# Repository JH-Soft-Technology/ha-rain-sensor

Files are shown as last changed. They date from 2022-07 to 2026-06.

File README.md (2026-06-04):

# Rain sensor for Home Assistant

A DIY wireless rain gauge built around a **Wemos D1 mini (ESP8266)** and the
**MS-WH-SP-RG** tipping-bucket sensor. It measures precipitation and reports it
to [Home Assistant](https://www.home-assistant.io/) over MQTT — with automatic
discovery, a built-in web dashboard, and over-the-air firmware updates.

- 🌧 **Accurate tip counting** — hardware interrupt with software debounce
- 📊 **Rich statistics** — total, rate (mm/h), today / week / month / year
- 🏠 **Home Assistant MQTT discovery** — entities appear automatically
- 🌐 **Built-in web dashboard** — live charts, served straight from the device
- 🔧 **Captive-portal setup** — pick WiFi + enter MQTT, no credentials in code
- ⬆️ **OTA updates** — flash new firmware from the browser
- ⏱ **NTP time sync** — correct daily / weekly / monthly / yearly resets

## Demo

You can try the device's web interface without any hardware — it is a static
snapshot of the real dashboard:

▶️ **[Live demo](https://htmlpreview.github.io/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)**

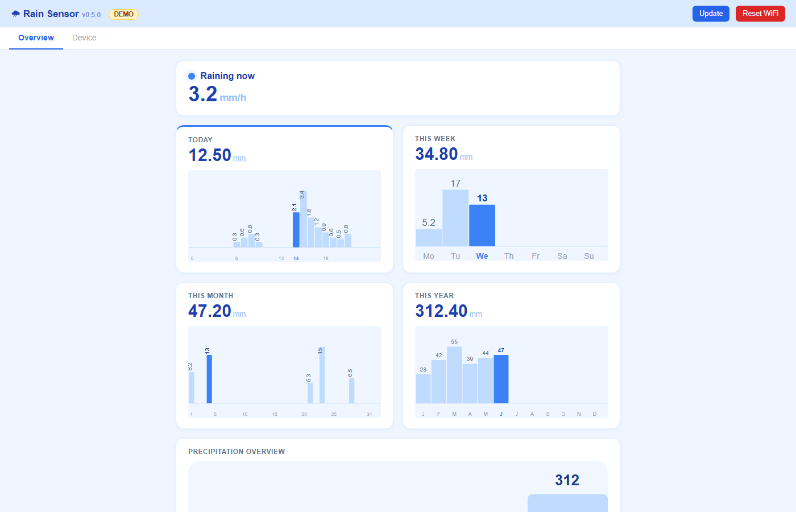
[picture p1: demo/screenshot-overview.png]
Web dashboard overview


## What's in this repository

| Path | Contents |
|---|---|
| `src/` | Firmware source (`main.cpp`) |
| `demo/` | Static preview of the web dashboard + screenshot |
| `home-assistant/` | Ready-to-use Home Assistant dashboard template |
| `3d_print/` | STL files for the sensor mount |
| `content/` | Wiring schematic and other images |
| `platformio.ini` | PlatformIO build configuration |
| `firmware-x.y.z.bin` | Pre-built firmware for OTA flashing |

## Used hardware

- Rain bucket sensor [MS-WH-SP-RG](https://www.laskakit.cz/ms-wh-sp-rg-srazkomer/)
- [Wemos D1 mini](https://www.laskakit.cz/wemos-d1-mini-esp8266-wifi-modul/) development board (4 MB flash, needed for OTA)

## Wiring

The rain gauge uses a reed (magnetic) switch on a ~2.9 m cable. The firmware
debounces the signal in software, but on a long cable a single noise spike can
be miscounted as a tip when using interrupts. A simple RC filter on the input is
recommended:

- `10 kΩ` pull-up from D1 to 3V3 (lower impedance than the internal pull-up)
- `100 nF` capacitor from D1 to GND (RC low-pass that smooths noise spikes)
- `1 kΩ` resistor in series with the reed switch (limits the capacitor's
  discharge current and protects the reed contacts)

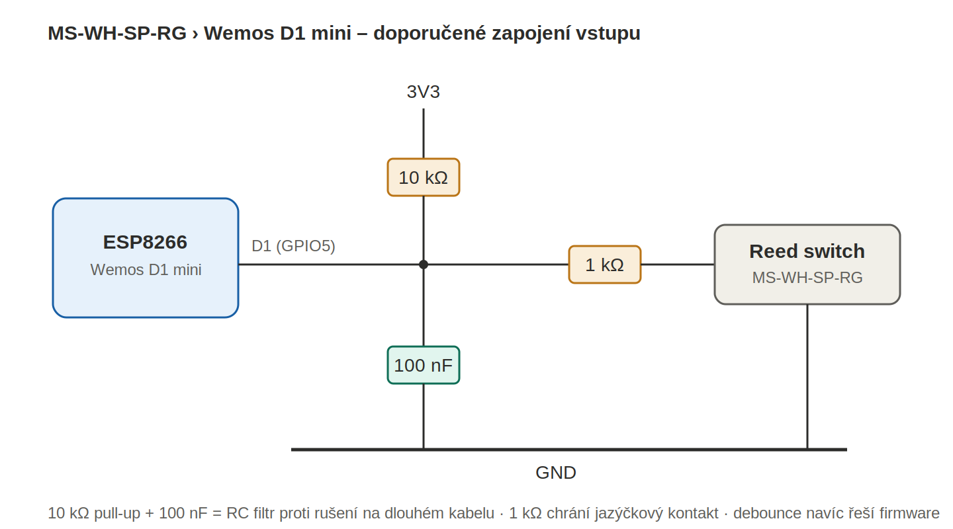
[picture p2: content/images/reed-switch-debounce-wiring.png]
Recommended input wiring


For a short cable next to the board the internal `INPUT_PULLUP` plus the
software debounce is usually enough.

## First-time setup (captive portal)

No credentials are stored in the source code. WiFi and MQTT are configured
through a captive portal on first boot:

1. Install the [MQTT](https://www.home-assistant.io/integrations/mqtt/) integration in Home Assistant and configure the broker.
2. Build and flash the firmware via PlatformIO (4 MB board, `littlefs` filesystem), or upload a pre-built `firmware-x.y.z.bin`.
3. On first boot the device opens a WiFi access point named **`RainSensor-Setup`**. Connect to it with a phone or laptop.
4. In the portal, pick your WiFi network, enter its password, and fill in the MQTT host, port, user and password. Save.
5. The device reboots, connects, and a new rain sensor device appears in the MQTT integration automatically.

Settings are stored on the device (LittleFS), so they survive reboots and
firmware updates.

## Web dashboard and OTA updates

Once connected, the device serves a dashboard on its IP address (shown in the
serial log and your router). It has two tabs:

- **Overview** — "raining now" with current rate, plus today / week / month / year totals, each with a bar chart.
- **Device** — IP address, WiFi signal, MQTT status, uptime, free memory and total rain since boot.

Two actions are available from the header:

- **Update** (`/update`) — upload a new firmware `.bin` straight from the browser (ElegantOTA).
- **Reset WiFi** (`/resetwifi`) — clear WiFi settings and reopen the setup portal.

The [live demo](https://htmlpreview.github.io/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) shows exactly this interface.

## Entities exposed in Home Assistant

All values are sent in a single JSON message and split into entities via value
templates, so the device only publishes one MQTT message per update.

| Entity | Type | Unit | Notes |
|---|---|---|---|
| Rain | sensor | mm | cumulative, `state_class: total_increasing` |
| Rain rate | sensor | mm/h | `device_class: precipitation_intensity` |
| Rain today | sensor | mm | resets at local midnight |
| Rain this week | sensor | mm | resets Monday |
| Rain this month | sensor | mm | resets on the 1st |
| Rain this year | sensor | mm | resets on Jan 1 |
| Raining | binary_sensor | — | on while it rained in the last 6 min |
| WiFi signal | sensor | dBm | diagnostic |
| Uptime | sensor | s | diagnostic |
| Free memory | sensor | B | diagnostic |

The period totals reset on real calendar boundaries thanks to **NTP time sync**
(CET/CEST). The cumulative rain uses `total_increasing`, so Home Assistant
tracks resets (after a reboot) and can build its own long-term statistics.

The send interval adapts automatically: **every 60 s** while it is raining,
**every 30 min** after 20 minutes without rain.

## Recreate the device dashboard in Home Assistant

The per-hour / per-day / per-month bar charts you see on the device are rendered
locally and are **not** sent over MQTT — there is no need to. Home Assistant can
rebuild them from the cumulative `Rain` sensor (`total_increasing`), which feeds
HA's long-term statistics.

A ready-to-use template is provided in
[`home-assistant/rain-sensor-homeassistant.yaml`](home-assistant/rain-sensor-homeassistant.yaml). It contains:

- `utility_meter` helpers for today / week / month / year (HA-side resets)
- a Lovelace dashboard mirroring the device's **Overview** and **Device** tabs, with bar charts built from the built-in `statistics-graph` card (no HACS required)
- an optional ApexCharts variant for nicer bars

Check the entity IDs at the top of the file against your install
(Settings → Devices & Services → Entities) before pasting it in.

## Build and development

- [Visual Studio Code](https://code.visualstudio.com/) with the [PlatformIO](https://platformio.org/) extension.
- Open the project, connect the Wemos D1 mini, and run *Upload*. After the first flash, further updates can be done over WiFi from the `/update` page.

## STL files

Pipe holder (50 mm diameter) with an arm to hold the rain sensor. Uses 6 M4
screws with nuts; the sensor is bolted to the arm with a self-tapping screw.

- [Pipe holder part 1](https://github.com/JH-Soft-Technology/ha-rain-sensor/blob/master/3d_print/rain%20sensor%20tube%20holder%20part%201.stl)
- [Pipe holder part 2](https://github.com/JH-Soft-Technology/ha-rain-sensor/blob/master/3d_print/rain%20sensor%20tube%20holder%20part%202.stl)
- [Arm holder](https://github.com/JH-Soft-Technology/ha-rain-sensor/blob/master/3d_print/Rain%20sensor%20arm.stl)

---

buy me a coffee (https://www.buymeacoffee.com/jhoralek)

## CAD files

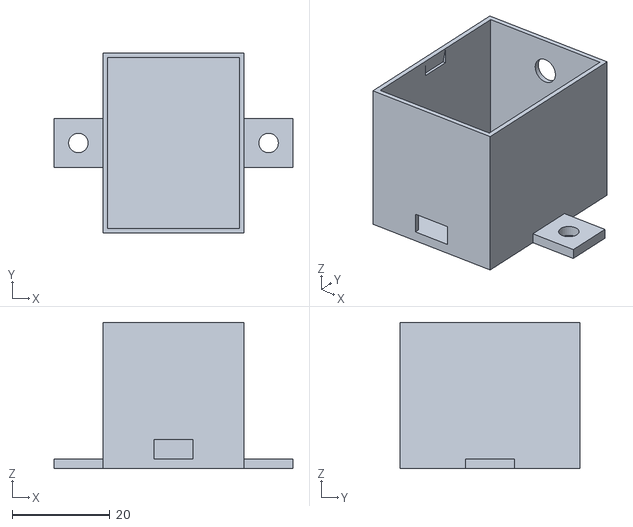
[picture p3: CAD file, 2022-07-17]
3d_print/wemos d1 mini box.stl
49.0 x 37.0 x 30.0

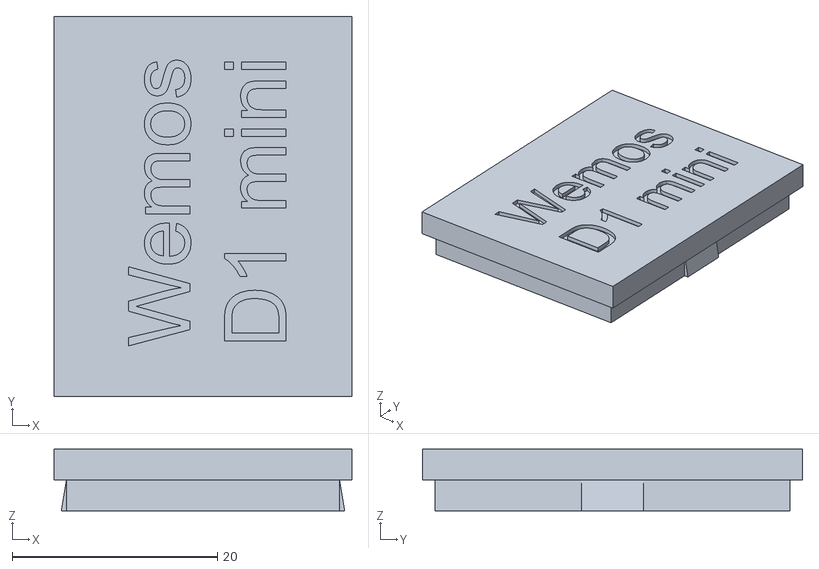
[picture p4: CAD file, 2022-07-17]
3d_print/wemos d1 mini box lid.stl
29.0 x 37.0 x 6.00

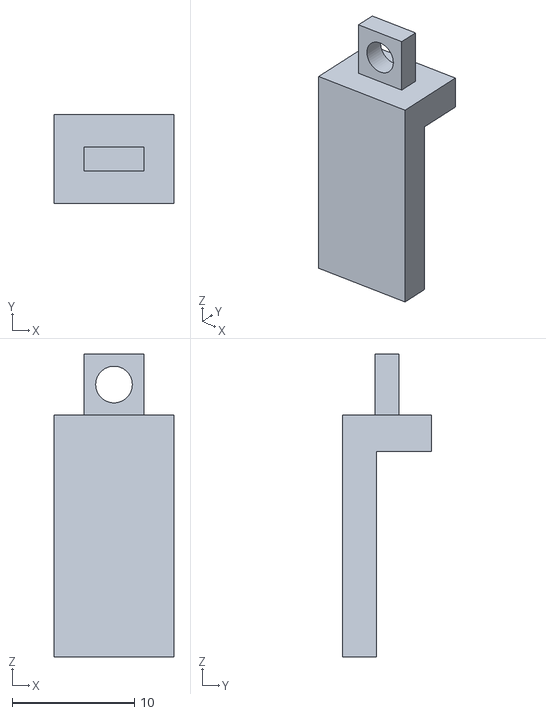
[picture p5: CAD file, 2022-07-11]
3d_print/rain sensor secure pin.stl
9.80 x 7.30 x 24.8

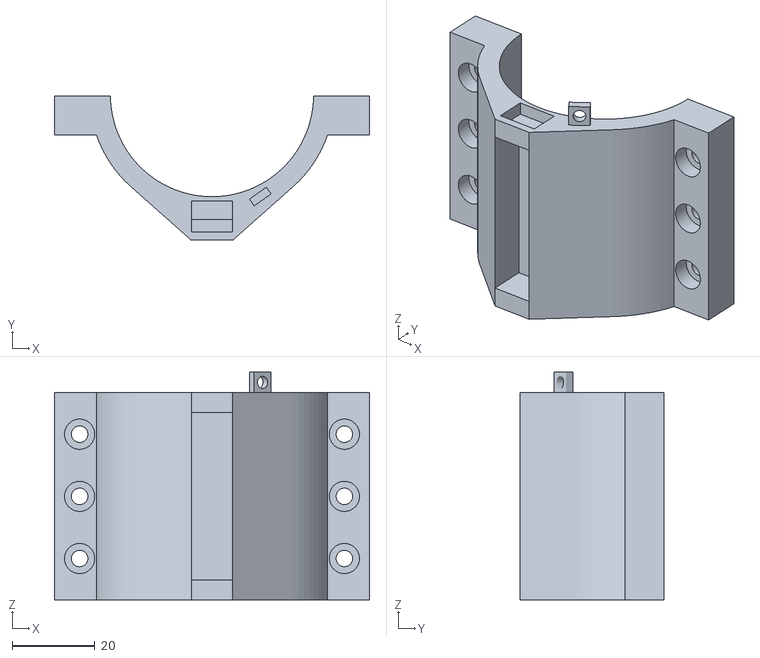
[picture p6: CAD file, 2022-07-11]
3d_print/rain sensor tube holder part 1.stl
76.0 x 34.9 x 55.0

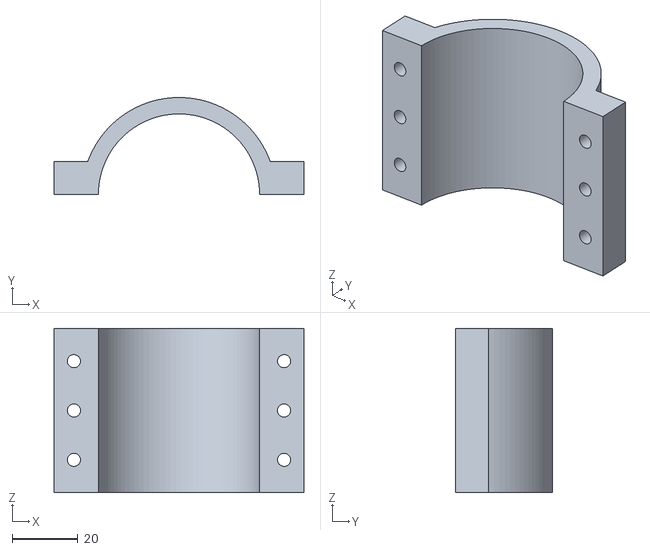
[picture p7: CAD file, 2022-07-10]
3d_print/rain sensor tube holder part 2.stl
76.0 x 29.5 x 50.0

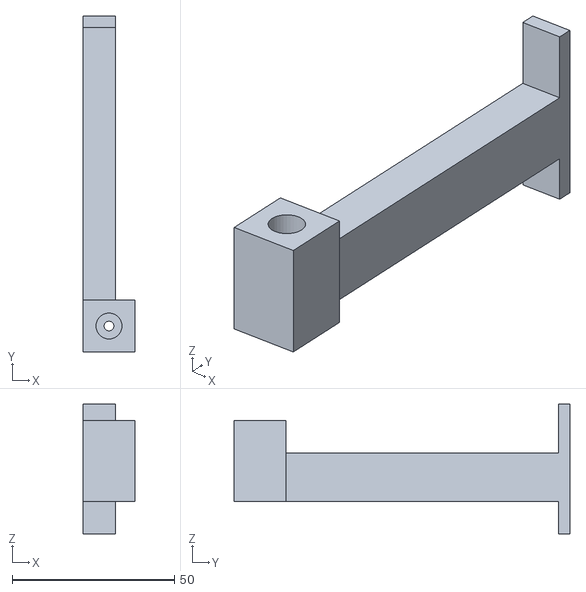
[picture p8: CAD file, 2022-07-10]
3d_print/Rain sensor arm.stl
16.0 x 103.5 x 40.0

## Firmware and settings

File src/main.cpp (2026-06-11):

/*
  Rain sensor for Home Assistant based on MQTT discovery.

  Features:
    - WiFi + MQTT configuration via a captive portal (WiFiManager),
      no credentials are stored in source code.
    - Web UI with live status, precipitation period totals, firmware
      update (ElegantOTA) and a "reset WiFi" button.
    - NTP time sync (CET/CEST) for daily/weekly/monthly/yearly reset.
    - Period stats (today/week/month/year) persisted to LittleFS.
    - One JSON state message exposed in HA as several entities:
      cumulative rain (mm), rain rate (mm/h), raining (binary),
      today/week/month/year rain, WiFi RSSI, uptime and free heap.

  author: Jiri Horalek
  email: horalek.jiri@gmail.com
  site: https://github.com/JH-Soft-Technology/ha-rain-sensor
  version: 0.7.1
  last change: 05.06.2026
*/
#include <Arduino.h>
#include <ESP8266WiFi.h>
#include <ESP8266WebServer.h>
#include <WiFiManager.h>
#include <LittleFS.h>
#include <PubSubClient.h>
#include <ArduinoJson.h>
#include <ElegantOTA.h>
#include <time.h>

#define MODEL "rainy 0.0.2"
#define SW_VERSION "0.7.1"

#define MQTT_MAX_TRANSFER_SIZE 1024
#define MQTT_INSTANCE_NAME "ha-rain-sensor"

#define AP_NAME "RainSensor-Setup"

#define RAIN_ACTIVE_INTERVAL_S 60
#define RAIN_IDLE_INTERVAL_S 1800

// Adaptive "raining" detection. A tipping bucket is quantized (one tip =
// 0.2794 mm), so in light rain the gap between tips can be tens of minutes
// and a fixed window flickers to "not raining" between tips. Instead we
// wait ~FACTOR x the last gap between tips, clamped to [MIN, MAX]:
// heavy rain -> short timeout (turns off quickly after it stops),
// drizzle    -> long timeout  (does not flicker during long gaps).
#define RAIN_TIMEOUT_FACTOR 2
#define RAIN_MIN_TIMEOUT_MS 600000UL   // 10 min
#define RAIN_MAX_TIMEOUT_MS 3600000UL  // 60 min

#define MQTT_RECONNECT_INTERVAL_MS 5000
#define DEBOUNCE_MS 150

#define NTP_SERVER "pool.ntp.org"
#define TZ_INFO "CET-1CEST,M3.5.0,M10.5.0/3"
#define STATS_SAVE_MS 300000UL // persist period stats every 5 min

// ---- MQTT discovery topics ----
#define TOPIC_STATE "homeassistant/sensor/" MQTT_INSTANCE_NAME "/state"
#define TOPIC_AVAILABILITY "homeassistant/sensor/" MQTT_INSTANCE_NAME "/availability"
#define PAYLOAD_ONLINE "online"
#define PAYLOAD_OFFLINE "offline"

#define CFG_RAIN "homeassistant/sensor/" MQTT_INSTANCE_NAME "/rain/config"
#define CFG_RATE "homeassistant/sensor/" MQTT_INSTANCE_NAME "/rate/config"
#define CFG_RSSI "homeassistant/sensor/" MQTT_INSTANCE_NAME "/rssi/config"
#define CFG_UPTIME "homeassistant/sensor/" MQTT_INSTANCE_NAME "/uptime/config"
#define CFG_HEAP "homeassistant/sensor/" MQTT_INSTANCE_NAME "/heap/config"
#define CFG_RAINING "homeassistant/binary_sensor/" MQTT_INSTANCE_NAME "/raining/config"
#define CFG_TODAY "homeassistant/sensor/" MQTT_INSTANCE_NAME "/today/config"
#define CFG_WEEK "homeassistant/sensor/" MQTT_INSTANCE_NAME "/week/config"
#define CFG_MONTH "homeassistant/sensor/" MQTT_INSTANCE_NAME "/month/config"
#define CFG_YEAR "homeassistant/sensor/" MQTT_INSTANCE_NAME "/year/config"

// On the Wemos D1 mini (ESP8266) all GPIO pins except D0 (GPIO16)
// support hardware interrupts, so D1 works fine with attachInterrupt.
const byte RAIN_PIN = D1;
const float MM_PER_TIP = 0.2794;

// ---- persisted MQTT configuration ----
struct Config
{
  char host[40];
  char port[6];
  char user[32];
  char pass[32];
};
Config config;
bool shouldSaveConfig = false;

WiFiClient wifi;
PubSubClient mqtt(wifi);
ESP8266WebServer server(80);
WiFiManager wm;

volatile unsigned int tipping_count = 0;
volatile unsigned long last_tip_time = 0;
volatile unsigned long last_tip_interval = 0; // gap (ms) between the last two tips

float total_rain_mm = 0.0;

// Period statistics — reset daily/weekly/monthly/yearly via NTP time
float rain_today_mm = 0.0;
float rain_week_mm = 0.0;
float rain_month_mm = 0.0;
float rain_year_mm = 0.0;

// Reference timestamps stored alongside period stats in LittleFS
int ref_yday = -1;  // tm_yday at last save (0–365)
int ref_week = -1;  // ISO week number at last save
int ref_month = -1; // tm_mon at last save (0–11)
int ref_year = -1;  // tm_year at last save (years since 1900)

// Per-bucket history arrays for in-tile sparkline charts
float rain_hourly[24] = {};      // rain per hour of today     (index = tm_hour)
float rain_daily_week[7] = {};   // rain per weekday Mon–Sun   (index = (wday+6)%7)
float rain_daily_month[31] = {}; // rain per day of month      (index = tm_mday-1)
float rain_monthly[12] = {};     // rain per month of year     (index = tm_mon)

int hist_hour = -1; // current accumulation bucket indices (updated each minute)
int hist_wday = -1;
int hist_mday = -1;
int hist_mon = -1;

unsigned long last_send_rain = 0;
unsigned long last_mqtt_attempt = 0;
unsigned long last_stats_save = 0;
unsigned long last_rollover_chk = 0;

// ---- ISR + tip helpers ----

IRAM_ATTR void count_tipping()
{
  unsigned long now = millis();
  if (now - last_tip_time > DEBOUNCE_MS)
  {
    if (last_tip_time != 0) last_tip_interval = now - last_tip_time;
    tipping_count++;
    last_tip_time = now;
  }
}

unsigned int peek_tips()
{
  noInterrupts();
  unsigned int c = tipping_count;
  interrupts();
  return c;
}

void consume_tips(unsigned int n)
{
  noInterrupts();
  tipping_count -= n;
  interrupts();
}

// How long without a tip until we decide it stopped raining. Scales with
// the last gap between tips so light rain doesn't flicker, clamped so heavy
// rain turns off promptly and a lone tip doesn't latch "raining" forever.
unsigned long rain_timeout_ms()
{
  unsigned long t = (unsigned long)RAIN_TIMEOUT_FACTOR * last_tip_interval;
  if (t < RAIN_MIN_TIMEOUT_MS) t = RAIN_MIN_TIMEOUT_MS;
  if (t > RAIN_MAX_TIMEOUT_MS) t = RAIN_MAX_TIMEOUT_MS;
  return t;
}

boolean raining_now()
{
  if (last_tip_time == 0) return false; // no tip ever -> not raining
  return (millis() - last_tip_time) < rain_timeout_ms();
}

// Rain rate (mm/h) derived from the interval between tips, not from counting
// tips in a fixed window. A tipping bucket is quantized (one tip = 0.2794 mm),
// so counting per minute reads 0 between tips and spikes on the tip. Using the
// gap between tips gives a smooth value: rate = mm_per_tip / gap. As time since
// the last tip grows past that gap, the rate decays; once raining_now() expires
// it returns 0.
float rain_rate_mm_h()
{
  if (last_tip_interval == 0) return 0.0; // need >= 2 tips to know a rate
  if (!raining_now()) return 0.0;         // rain stopped (adaptive timeout)
  unsigned long since = millis() - last_tip_time;
  unsigned long gap = (since > last_tip_interval) ? since : last_tip_interval;
  return MM_PER_TIP / (gap / 3600000.0);
}

// ---- Time helpers ----

boolean get_localtime(struct tm &ti)
{
  time_t now = time(nullptr);
  if (now < 1000000000UL)
    return false;
  localtime_r(&now, &ti);
  return true;
}

// Monday-based ISO week number (strftime %W).
int week_num(const struct tm &ti)
{
  char buf[4];
  strftime(buf, sizeof(buf), "%W", &ti);
  return atoi(buf);
}

void sync_ntp()
{
  configTime(0, 0, NTP_SERVER);
  setenv("TZ", TZ_INFO, 1);
  tzset();
  Serial.print("Waiting for NTP ...");
  time_t now = 0;
  for (int i = 0; i < 50 && now < 1000000000UL; i++)
  {
    delay(100);
    time(&now);
  }
  Serial.println(now > 1000000000UL ? " OK" : " failed");
}

// ---- Period-stats persistence (LittleFS /stats.json) ----

void load_stats()
{
  if (!LittleFS.exists("/stats.json"))
    return;
  File f = LittleFS.open("/stats.json", "r");
  if (!f)
    return;
  DynamicJsonDocument doc(400);
  if (deserializeJson(doc, f))
  {
    f.close();
    return;
  }
  f.close();
  total_rain_mm = doc["total"] | 0.0f;
  rain_today_mm = doc["today"] | 0.0f;
  rain_week_mm = doc["week"] | 0.0f;
  rain_month_mm = doc["month"] | 0.0f;
  rain_year_mm = doc["yr"] | 0.0f;
  ref_yday = doc["yday"] | -1;
  ref_week = doc["wk"] | -1;
  ref_month = doc["mon"] | -1;
  ref_year = doc["year"] | -1;
}

void save_stats()
{
  DynamicJsonDocument doc(400);
  doc["total"] = total_rain_mm;
  doc["today"] = rain_today_mm;
  doc["week"] = rain_week_mm;
  doc["month"] = rain_month_mm;
  doc["yr"] = rain_year_mm;
  doc["yday"] = ref_yday;
  doc["wk"] = ref_week;
  doc["mon"] = ref_month;
  doc["year"] = ref_year;
  File f = LittleFS.open("/stats.json", "w");
  if (!f)
    return;
  serializeJson(doc, f);
  f.close();
}

void save_history(); // defined below, forward-declared for check_rollover

// Reset period accumulators that have rolled over since the last save.
void check_rollover()
{
  struct tm ti;
  if (!get_localtime(ti))
    return;

  int cur_yday = ti.tm_yday;
  int cur_week = week_num(ti);
  int cur_month = ti.tm_mon;
  int cur_year = ti.tm_year;

  // Always keep current-bucket indices up to date
  hist_hour = ti.tm_hour;
  hist_wday = (ti.tm_wday + 6) % 7; // Mon=0 … Sun=6
  hist_mday = ti.tm_mday - 1;
  hist_mon = ti.tm_mon;

  if (ref_year == -1)
  {
    ref_yday = cur_yday;
    ref_week = cur_week;
    ref_month = cur_month;
    ref_year = cur_year;
    save_stats();
    return;
  }

  bool changed = false;

  if (cur_year != ref_year)
  {
    rain_year_mm = rain_month_mm = rain_week_mm = rain_today_mm = 0;
    memset(rain_monthly, 0, sizeof(rain_monthly));
    memset(rain_daily_month, 0, sizeof(rain_daily_month));
    memset(rain_daily_week, 0, sizeof(rain_daily_week));
    memset(rain_hourly, 0, sizeof(rain_hourly));
    ref_year = cur_year;
    ref_month = cur_month;
    ref_week = cur_week;
    ref_yday = cur_yday;
    changed = true;
  }
  else if (cur_month != ref_month)
  {
    rain_month_mm = rain_week_mm = rain_today_mm = 0;
    memset(rain_daily_month, 0, sizeof(rain_daily_month));
    memset(rain_daily_week, 0, sizeof(rain_daily_week));
    memset(rain_hourly, 0, sizeof(rain_hourly));
    ref_month = cur_month;
    ref_week = cur_week;
    ref_yday = cur_yday;
    changed = true;
  }
  else if (cur_week != ref_week)
  {
    rain_week_mm = rain_today_mm = 0;
    memset(rain_daily_week, 0, sizeof(rain_daily_week));
    memset(rain_hourly, 0, sizeof(rain_hourly));
    ref_week = cur_week;
    ref_yday = cur_yday;
    changed = true;
  }
  else if (cur_yday != ref_yday)
  {
    rain_today_mm = 0;
    memset(rain_hourly, 0, sizeof(rain_hourly));
    ref_yday = cur_yday;
    changed = true;
  }

  if (changed)
  {
    save_stats();
    save_history();
  }
}

// ---- MQTT configuration persistence (LittleFS /config.json) ----

boolean load_config()
{
  if (!LittleFS.exists("/config.json"))
    return false;
  File f = LittleFS.open("/config.json", "r");
  if (!f)
    return false;
  DynamicJsonDocument doc(512);
  DeserializationError err = deserializeJson(doc, f);
  f.close();
  if (err)
    return false;
  strlcpy(config.host, doc["host"] | "", sizeof(config.host));
  strlcpy(config.port, doc["port"] | "1883", sizeof(config.port));
  strlcpy(config.user, doc["user"] | "", sizeof(config.user));
  strlcpy(config.pass, doc["pass"] | "", sizeof(config.pass));
  return true;
}

void save_config()
{
  DynamicJsonDocument doc(512);
  doc["host"] = config.host;
  doc["port"] = config.port;
  doc["user"] = config.user;
  doc["pass"] = config.pass;
  File f = LittleFS.open("/config.json", "w");
  if (!f)
  {
    Serial.println("Failed to open config file for writing");
    return;
  }
  serializeJson(doc, f);
  f.close();
  Serial.println("Config saved");
}

void load_history()
{
  if (!LittleFS.exists("/history.json"))
    return;
  File f = LittleFS.open("/history.json", "r");
  if (!f)
    return;
  DynamicJsonDocument doc(1024);
  if (deserializeJson(doc, f))
  {
    f.close();
    return;
  }
  f.close();
  JsonArray ah = doc["h"].as<JsonArray>();
  JsonArray aw = doc["w"].as<JsonArray>();
  JsonArray am = doc["m"].as<JsonArray>();
  JsonArray ay = doc["y"].as<JsonArray>();
  for (int i = 0; i < (int)ah.size() && i < 24; i++)
    rain_hourly[i] = ah[i] | 0.0f;
  for (int i = 0; i < (int)aw.size() && i < 7; i++)
    rain_daily_week[i] = aw[i] | 0.0f;
  for (int i = 0; i < (int)am.size() && i < 31; i++)
    rain_daily_month[i] = am[i] | 0.0f;
  for (int i = 0; i < (int)ay.size() && i < 12; i++)
    rain_monthly[i] = ay[i] | 0.0f;
}

void save_history()
{
  DynamicJsonDocument doc(1024);
  JsonArray ah = doc.createNestedArray("h");
  JsonArray aw = doc.createNestedArray("w");
  JsonArray am = doc.createNestedArray("m");
  JsonArray ay = doc.createNestedArray("y");
  for (int i = 0; i < 24; i++)
    ah.add(round(rain_hourly[i] * 100) / 100.0f);
  for (int i = 0; i < 7; i++)
    aw.add(round(rain_daily_week[i] * 100) / 100.0f);
  for (int i = 0; i < 31; i++)
    am.add(round(rain_daily_month[i] * 100) / 100.0f);
  for (int i = 0; i < 12; i++)
    ay.add(round(rain_monthly[i] * 100) / 100.0f);
  File f = LittleFS.open("/history.json", "w");
  if (!f)
    return;
  serializeJson(doc, f);
  f.close();
}

void save_config_callback() { shouldSaveConfig = true; }

// ---- Home Assistant MQTT discovery ----

void add_device_info(JsonObject device)
{
  JsonArray ids = device.createNestedArray("ids");
  ids.add(MQTT_INSTANCE_NAME);
  device["mf"] = "JH SOFT Technology";
  device["mdl"] = MODEL;
  device["name"] = "Rain sensor";
  device["sw"] = SW_VERSION;
}

DynamicJsonDocument build_sensor_config(const char *name, const char *uniq,
                                        const char *val_tpl, const char *unit,
                                        const char *dev_cla, const char *stat_cla,
                                        const char *icon, boolean diagnostic)
{
  DynamicJsonDocument c(1024);
  c["name"] = name;
  c["uniq_id"] = uniq;
  c["stat_t"] = TOPIC_STATE;
  c["val_tpl"] = val_tpl;
  if (unit)
    c["unit_of_meas"] = unit;
  if (dev_cla)
    c["dev_cla"] = dev_cla;
  if (stat_cla)
    c["stat_cla"] = stat_cla;
  if (icon)
    c["icon"] = icon;
  if (diagnostic)
    c["ent_cat"] = "diagnostic";
  c["avty_t"] = TOPIC_AVAILABILITY;
  c["pl_avail"] = PAYLOAD_ONLINE;
  c["pl_not_avail"] = PAYLOAD_OFFLINE;
  add_device_info(c.createNestedObject("dev"));
  return c;
}

DynamicJsonDocument build_raining_config()
{
  DynamicJsonDocument c(1024);
  c["name"] = "Raining";
  c["uniq_id"] = "rain_sensor_raining";
  c["stat_t"] = TOPIC_STATE;
  c["val_tpl"] = "{{ 'ON' if value_json.raining else 'OFF' }}";
  c["dev_cla"] = "moisture";
  c["icon"] = "mdi:weather-pouring";
  c["avty_t"] = TOPIC_AVAILABILITY;
  c["pl_avail"] = PAYLOAD_ONLINE;
  c["pl_not_avail"] = PAYLOAD_OFFLINE;
  add_device_info(c.createNestedObject("dev"));
  return c;
}

// ---- MQTT ----

boolean mqtt_reconnect()
{
  if (mqtt.connected())
    return true;
  if (millis() - last_mqtt_attempt < MQTT_RECONNECT_INTERVAL_MS)
    return false;
  last_mqtt_attempt = millis();
  Serial.print("Connecting to mqtt broker ...");
  boolean connected;
  if (strlen(config.user) > 0)
    connected = mqtt.connect(MQTT_INSTANCE_NAME, config.user, config.pass,
                             TOPIC_AVAILABILITY, 0, true, PAYLOAD_OFFLINE);
  else
    connected = mqtt.connect(MQTT_INSTANCE_NAME, NULL, NULL,
                             TOPIC_AVAILABILITY, 0, true, PAYLOAD_OFFLINE);
  if (!connected)
  {
    Serial.print(" failed, rc=");
    Serial.println(mqtt.state());
    return false;
  }
  Serial.println(" connected");
  mqtt.publish(TOPIC_AVAILABILITY, PAYLOAD_ONLINE, true);
  return true;
}

boolean publish_config(DynamicJsonDocument doc, const char *topic)
{
  char buffer[MQTT_MAX_TRANSFER_SIZE];
  size_t n = serializeJson(doc, buffer, sizeof(buffer));
  if (!n)
  {
    Serial.println("Config serialization failed (buffer too small)");
    return false;
  }
  return mqtt.publish(topic, buffer, true);
}

void publish_discovery()
{
  publish_config(build_sensor_config(
                     "Rain", "rain_sensor",
                     "{{ value_json.rain }}", "mm",
                     "precipitation", "total_increasing", "mdi:weather-rainy", false),
                 CFG_RAIN);

  publish_config(build_sensor_config(
                     "Rain rate", "rain_sensor_rate",
                     "{{ value_json.rate }}", "mm/h",
                     "precipitation_intensity", "measurement", "mdi:weather-pouring", false),
                 CFG_RATE);

  publish_config(build_sensor_config(
                     "Rain today", "rain_sensor_today",
                     "{{ value_json.today }}", "mm",
                     "precipitation", "measurement", "mdi:weather-rainy", false),
                 CFG_TODAY);

  publish_config(build_sensor_config(
                     "Rain this week", "rain_sensor_week",
                     "{{ value_json.week }}", "mm",
                     "precipitation", "measurement", "mdi:calendar-week", false),
                 CFG_WEEK);

  publish_config(build_sensor_config(
                     "Rain this month", "rain_sensor_month",
                     "{{ value_json.month }}", "mm",
                     "precipitation", "measurement", "mdi:calendar-month", false),
                 CFG_MONTH);

  publish_config(build_sensor_config(
                     "Rain this year", "rain_sensor_year",
                     "{{ value_json.year }}", "mm",
                     "precipitation", "measurement", "mdi:calendar", false),
                 CFG_YEAR);

  publish_config(build_sensor_config(
                     "WiFi signal", "rain_sensor_rssi",
                     "{{ value_json.rssi }}", "dBm",
                     "signal_strength", "measurement", NULL, true),
                 CFG_RSSI);

  publish_config(build_sensor_config(
                     "Uptime", "rain_sensor_uptime",
                     "{{ value_json.uptime }}", "s",
                     "duration", "measurement", NULL, true),
                 CFG_UPTIME);

  publish_config(build_sensor_config(
                     "Free memory", "rain_sensor_heap",
                     "{{ value_json.heap }}", "B",
                     NULL, "measurement", "mdi:memory", true),
                 CFG_HEAP);

  publish_config(build_raining_config(), CFG_RAINING);
}

boolean publish_state()
{
  if (!mqtt.connected())
    return false;
  DynamicJsonDocument doc(384);
  doc["rain"] = round(total_rain_mm * 100) / 100.0;
  doc["rate"] = round(rain_rate_mm_h() * 10) / 10.0;
  doc["raining"] = raining_now();
  doc["rssi"] = WiFi.RSSI();
  doc["uptime"] = millis() / 1000UL;
  doc["heap"] = ESP.getFreeHeap();
  doc["today"] = round(rain_today_mm * 100) / 100.0;
  doc["week"] = round(rain_week_mm * 100) / 100.0;
  doc["month"] = round(rain_month_mm * 100) / 100.0;
  doc["year"] = round(rain_year_mm * 100) / 100.0;
  char buffer[384];
  serializeJson(doc, buffer, sizeof(buffer));
  return mqtt.publish(TOPIC_STATE, buffer, true);
}

// ---- Web UI ----

// Stream a single x-axis label for a sparkline.
void send_xlabel(int idx, int bw, int y, int hi, int xfs, const char *lbl)
{
  int cx = 1 + idx * (bw + 1) + bw / 2;
  char buf[110];
  snprintf(buf, sizeof(buf),
           "<text x='%d' y='%d' font-size='%d' fill='%s'"
           " font-weight='%s' text-anchor='middle'>%s</text>",
           cx, y, xfs,
           idx == hi ? "#3b82f6" : "#94a3b8",
           idx == hi ? "700" : "400",
           lbl);
  server.sendContent(buf);
}
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
void loop()
{
  server.handleClient();

  if (WiFi.status() == WL_CONNECTED)
  {
    mqtt_reconnect();
    mqtt.loop();
  }

  // Accumulate tips into period totals and history buckets.
  unsigned int tips = peek_tips();
  if (tips > 0)
  {
    consume_tips(tips);
    float mm = tips * MM_PER_TIP;
    total_rain_mm += mm;
    rain_today_mm += mm;
    rain_week_mm += mm;
    rain_month_mm += mm;
    rain_year_mm += mm;
    if (hist_hour >= 0)
      rain_hourly[hist_hour] += mm;
    if (hist_wday >= 0)
      rain_daily_week[hist_wday] += mm;
    if (hist_mday >= 0)
      rain_daily_month[hist_mday] += mm;
    if (hist_mon >= 0)
      rain_monthly[hist_mon] += mm;
  }

  // Check for day/week/month/year rollover once per minute.
  if (millis() - last_rollover_chk > 60000UL)
  {
    last_rollover_chk = millis();
    check_rollover();
  }

  // Persist stats and history periodically to survive power loss.
  if (millis() - last_stats_save > STATS_SAVE_MS)
  {
    last_stats_save = millis();
    save_stats();
    save_history();
  }

  unsigned long interval_ms = raining_now()
                                  ? RAIN_ACTIVE_INTERVAL_S * 1000UL
                                  : RAIN_IDLE_INTERVAL_S * 1000UL;

  if (millis() - last_send_rain > interval_ms)
  {
    if (publish_state())
      last_send_rain = millis();
  }
}

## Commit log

2022-07-10 - wifi comunication - broker communication - device definition - payload serialized
    [main.cpp]
2022-07-10 3d print stl files and images with wiring
    [Rain sensor arm.stl, rain sensor tube holder part 1.stl, rain sensor tube holder part 2.stl]
2022-07-11 change part 1 connecting with arm, add secure pin to hold arm on the place
    [rain sensor secure pin.stl, rain sensor tube holder part 1.stl]
2022-07-17 change send time interval to 10 min.
    [wemos d1 mini box lid.stl, wemos d1 mini box.stl]
2022-07-21 add distance sensor HC-SR04
2022-07-25 Add distance sensor. Used for checking if car is in parking lot.
2022-09-27 calculation correction
    The pulse from the rain gauge already "arrives" with an audible click - when flipped to one of the two end positions
    [main.cpp]
2026-06-03 Fix rain counting: use hardware interrupt with debounce
    - Replace polling count_tipping() with IRAM_ATTR ISR on FALLING edge
    (MS-WH-SP-RG reed switch closes to GND -> INPUT_PULLUP + FALLING)
    - Add 150ms software debounce to filter reed-switch contact bounce
    - Make tipping_count volatile (modified in ISR)
    - Make calculate_rain() atomic (noInterrupts) to avoid losing tips
    - Remove count_tipping() polling from loop()
    - Fix incorrect comment about D1 interrupt support
    This prevents missed/double-counted tips that caused inaccurate rainfall.
    [main.cpp]
2026-06-03 Refactor: HA discovery fix, availability/LWT, non-blocking reconnect
    - Fix HA MQTT discovery: identifiers as a proper JSON array, both
    entities grouped under one device, add device_class/state_class,
    remove invalid 'schema' key
    - Add availability via Last Will & Testament (online/offline)
    - Non-blocking WiFi and MQTT reconnect with timeouts (no more infinite
    while loops that could freeze the sensor)
    - Add mqtt.loop() to service the MQTT client
    - Measure distance once per cycle (was measured twice)
    - Fix buffer overflow in send_state_topic (sizeof(float) was too small)
    - Preserve rain tips on failed publish (subtract only what was sent)
    - Move WiFi/MQTT credentials to git-ignored includ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
    [main.cpp]
2026-06-03 Remove ultrasonic distance (parking-spot) sensor
    The firmware now exposes only the rain sensor. Removed the HC-SR04
    distance measurement, its discovery config, pins, topics and loop
    handling. Device name simplified to 'Rain sensor'. Version bumped to
    0.2.0. (MQTT instance id kept as-is to preserve the existing HA device
    identity.)
2026-06-03 Add recommended reed-switch input wiring schematic
2026-06-03 Document recommended input wiring (RC debounce)
2026-06-03 Adaptive send interval + cumulative total + MQTT rename
    - Adaptive interval: 60s during rain, 30min after 20min dry
    - Cumulative total_rain_mm with state_class total_increasing
    (HA auto-tracks resets, calculates hourly/daily statistics)
    - Rename MQTT instance to ha-rain-sensor
    - Version 0.3.0
    [main.cpp]
2026-06-03 Remove outdated image: MQTT-discovery-device-rain-sensor.png
2026-06-03 Remove outdated image: WeMos-d1-connect-to-ms-wh-sp-rg-rain-tipping-sensor.png
2026-06-03 Remove outdated image: WeMos-d1-connect-with-shield-to-ms-wh-sp-rg-rain-tipping-sensor.png
2026-06-03 Add web UI, ElegantOTA, WiFiManager portal + extended payload
    - WiFiManager captive portal for WiFi + MQTT config (no secrets.h)
    - Config persisted to LittleFS
    - ElegantOTA web firmware update at /update
    - Status web page at / with live metrics + reset WiFi button
    - Single JSON state -> 6 HA entities: rain (total_increasing),
    rain rate (precipitation_intensity), raining (binary), RSSI,
    uptime, free heap (last three diagnostic)
    - Version 0.4.0
    [main.cpp]
2026-06-03 Target 4MB d1_mini board; add WiFiManager, ElegantOTA, LittleFS
2026-06-04 feat: v0.6.0 — larger tiles, value labels and x-axis in sparkline charts
    - Wider web UI container (520px → 820px) so tiles have room to breathe
    - Larger 2×2 precipitation tiles (border-radius 14px, bigger padding/fonts)
    - Sparkline charts completely redesigned: viewBox 260×124 (was dynamic 28px)
    - Value labels above each bar (horizontal for weekly/yearly, rotated −90°
    for dense hourly/monthly charts)
    - X-axis labels per chart type: hours (0,6,12,hi,18), weekdays (Mo–Su),
    days of month (1,5,10,15,20,25,31), months (J–D)
    - Active bucket always highlighted in #3b82f6 with bold label
    - Summary bar chart enlarged: viewBox 340×180 (was 275×150), font 12/11px
    - send_xla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
    [main.cpp]
2026-06-05 Fix utility_meter on total_increasing source
    - Add periodically_resetting: false (cumulative source resets only on
    reboot, not per cycle) so the meters actually count
    - Mark the utility_meter section optional (firmware already exposes
    today/week/month/year entities)
    - Note possible sensor.rain_sensor_rain_sensor double-suffix from a
    leftover registry entity
2026-06-05 Correct cumulative-sensor note (no orphan entity assumption)
2026-06-05 Persist cumulative total_rain_mm across reboots
    The cumulative total (state_class total_increasing) was reset to 0 on
    every reboot because it was not saved to LittleFS, unlike the period
    totals. That broke Home Assistant statistics (sum/max came out wrong)
    for the daily/weekly/monthly rainfall charts.
    - Save total to /stats.json (load_stats/save_stats)
    - Bump stats JSON capacity 256 -> 320
    - Web label "Total since boot" -> "Total" (value now persists)
    - Version 0.6.1
    [main.cpp]
2026-06-05 fix print Total na karte device a nasledne jeho odstraneni neni tam vubec treba.
    [main.cpp]
2026-06-05 Adaptive raining detection based on tip interval
    A tipping bucket is quantized (one tip = 0.2794 mm), so in light rain the
    gap between tips can be tens of minutes and the fixed 6-min window made
    the binary raining sensor flicker to off between tips.
    - raining_now() now waits ~2x the last gap between tips, clamped to
    10-60 min (rain_timeout_ms): drizzle holds, heavy rain turns off fast,
    a lone tip does not latch raining for an hour
    - ISR records last_tip_interval (gap between the last two tips)
    - Guard: no tip ever -> not raining (fixes raining=true right after boot)
    - Send-interval switching now reuses raining_now() (removes the old
    inconsistency between the 6-min binary window and th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
    [main.cpp]
2026-06-09 HA template: use stat_types change instead of sum for daily bars
    statistics-graph plots sum as the cumulative value, so a bar chart of a
    total_increasing rain sensor showed the carried-forward total (e.g. 2mm
    on Sun, then 2mm Mon and Tue too). change shows the per-period delta, so
    each bar is the rainfall during that day/hour/month (Sun 2, Mon 0, Tue 0).
2026-06-09 Fix intermittent web server hang (socket exhaustion)
    The status page auto-refreshed every 10s and responses had no
    Connection: close. On the ESP8266 (only ~5 lwIP sockets) the repeated
    refresh connections were not freed promptly, so the web server
    eventually stopped accepting connections while MQTT (its own socket)
    kept publishing.
    - Remove the meta refresh entirely (page already renders live values on
    load; use F5 to refresh manually)
    - Send Connection: close so each request frees its socket
    - Version 0.6.3
    [main.cpp]
2026-06-09 Add web button to reset rainfall totals
    Adds a "Reset uhrnu srazek" button in the nav next to Reset WiFi. It
    opens a confirmation dialog (Potvrdit / Storno) describing what will
    happen, then GETs /resetrain which zeroes every accumulated value
    (total, today/week/month/year, hourly/daily/monthly history), persists
    the zeros to LittleFS so the reset survives reboot, pushes zeros to HA,
    and redirects back to the dashboard. Useful for clearing bogus data
    after test measurements. Version 0.7.0
    [main.cpp]
2026-06-10 Compute rain rate from tip interval, not a fixed window
    The rate was counted over the 60s send window and extrapolated to mm/h.
    A tipping bucket is quantized (one tip = 0.2794 mm), so in light rain
    most 60s windows have zero tips -> rate reads 0, and the single window
    with a tip spikes to 16.8 mm/h. Confirmed in HA history (0 / 16.8 / 0).
    Now rate = mm_per_tip / gap_between_tips, which is smooth and meaningful
    (e.g. tips ~20 min apart -> ~0.8 mm/h). The displayed rate decays as the
    gap since the last tip grows and returns 0 once raining_now() expires.
    - Add rain_rate_mm_h() from last_tip_interval
    - Use it in MQTT publish and web dashboard
    - Remove period_rain_mm and last_rate (windowed app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
    [main.cpp]
